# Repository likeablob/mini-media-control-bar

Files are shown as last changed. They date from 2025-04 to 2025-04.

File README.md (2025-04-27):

# mini-media-control-bar

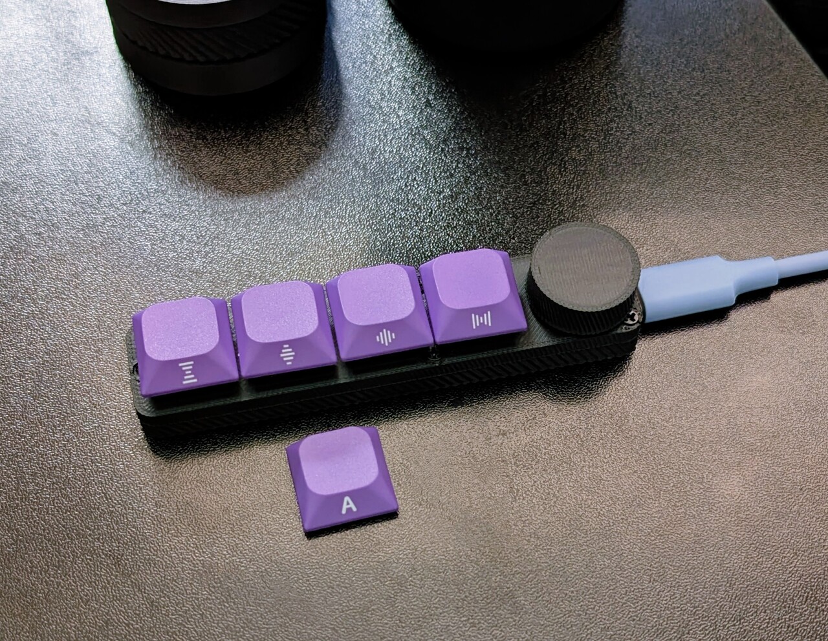
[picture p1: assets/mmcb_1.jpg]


A tiny media control bar based on ESPHome.

- **4 Keys + 1 Rotary Encoder Knob**
- **Acts as a BLE Keyboard with WiFi connectivity (ESP32-C3 Super Mini)**
- **Seamless Home Assistant integration via ESPHome**
- **Customizable 3D Printed Enclosure (designed in OpenSCAD)**

## BOM

| Component | Quantity | Notes |
| :--- | :--- | :--- |
| ESP32-C3 Super Mini | 1 | |
| Low-profile Cherry MX Switches | 4 | |
| Low-profile Keycaps | 4 | |
| Generic Mouse Rotary Encoder | 1 | 3-pin, H5.5mm x W9.5mm |
| Φ1.75mm PLA filament | - | Used as the shaft for the knob.  A short piece is needed. |
| Magnets (Optional) | 2 | Φ3mm x 6mm Neodymium (for mounting) |
| M2 x 6mm Self tapping screws | 5 | |
| Wire | - | |
| LOCTITE | - | |

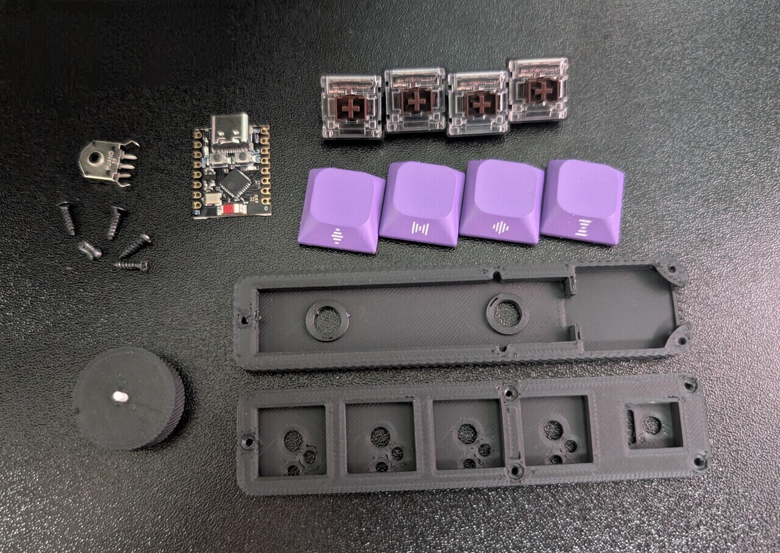
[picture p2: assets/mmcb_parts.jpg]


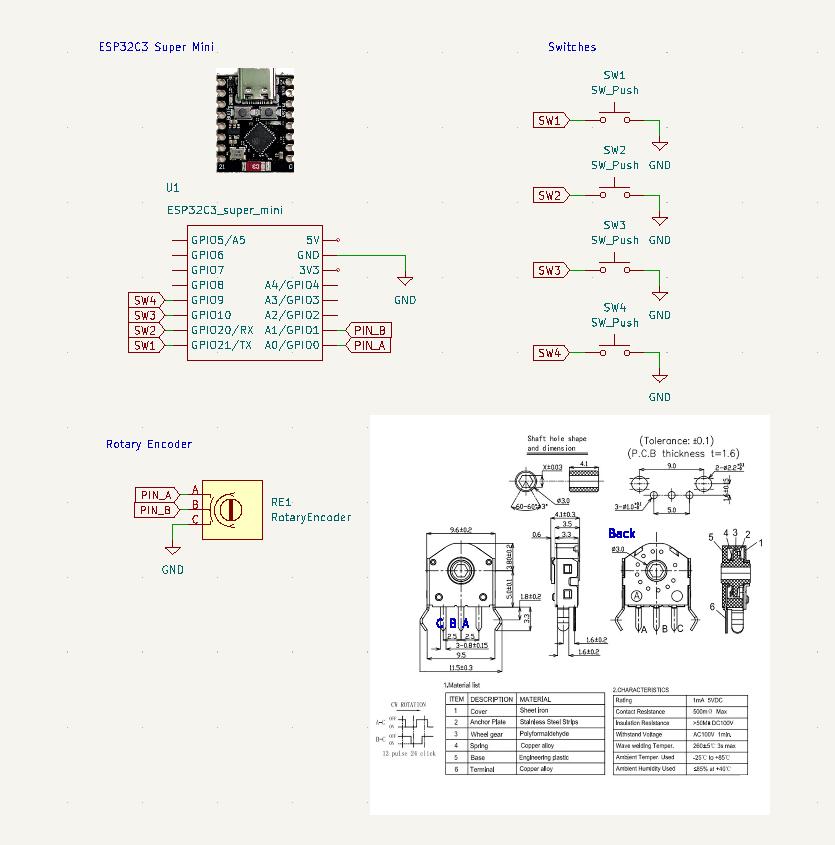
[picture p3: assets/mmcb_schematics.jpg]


## 3D Printed Parts

- See the [`./enclosure`](./enclosure/) directory.

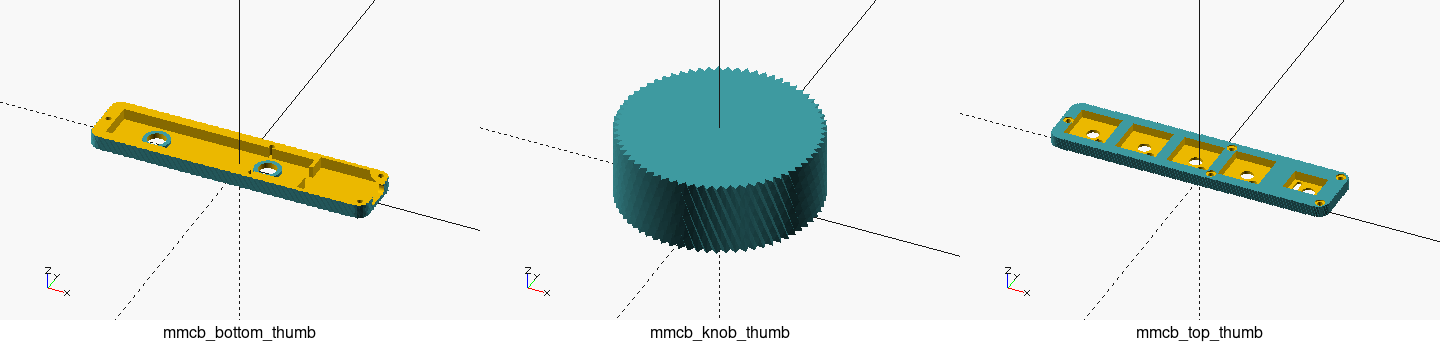
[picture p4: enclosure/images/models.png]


## Software

- The firmware is built using [ESPHome](https://esphome.io/). (`2025.3.3`)
- Reference the package definition [`mmcb.yaml`](./mmcb.yaml) via URL directly or download to your local.

```yaml
# In your esphome config file:
packages:
  mmcb:
    url: https://github.com/likeablob/mini-media-control-bar
    ref: main
    files:
      - path: mmcb.yaml
        vars:
          ble_device_name: "mmcb-1"

# or download to common/mmcb.yaml then reference it
packages:
  mmcb: !include
    file: common/mmcb.yaml
    vars:
      ble_device_name: "mmcb-1"
```

## Usage

| Key | Default | With Meta | Special |
| :--- | :--- | :--- | :--- |
| Key 1 (Left-most) | Meta key | N/A | Double-click: Mute |
| Key 2 | Play/Pause | Mute | |
| Key 3 | Previous track | Left arrow | |
| Key 4 | Next track | Right arrow | |
| Knob | Volume Up/Down | Right/Left arrow | |

See [`mmcb.yaml`](./mmcb.yaml) for configuration options.

## License

MIT

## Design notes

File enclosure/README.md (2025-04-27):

# mini-media-control-bar/case

## Prerequisites

- OpenSCAD (nightly build) 2025.02
- GNU Make
- ImageMagick
- BOSL2 (included as submodule)

## Build

```sh
$ git submodule update --init --recursive

# Generate .scad and .stl files.
$ make all -B

# Generate thumbnail images.
$ make images -B
```

## Parts

| | STL |
| --- | --- |
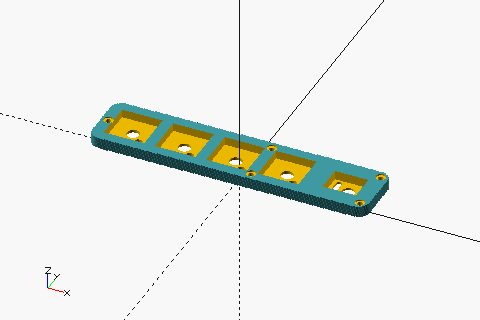
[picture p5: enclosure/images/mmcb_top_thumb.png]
|  | [mmcb_top.stl](./mmcb_top.stl) |
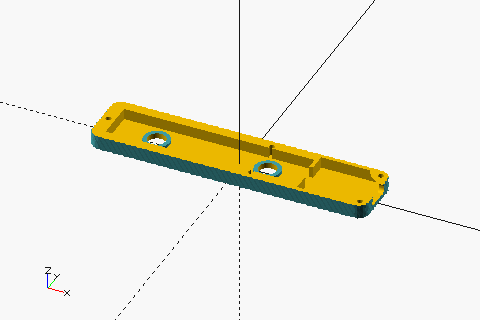
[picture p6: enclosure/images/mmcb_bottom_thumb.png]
|  | [mmcb_bottom.stl](./mmcb_bottom.stl) |
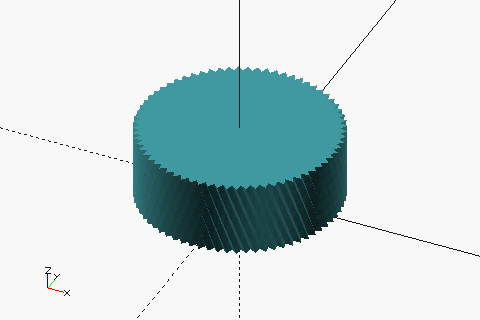
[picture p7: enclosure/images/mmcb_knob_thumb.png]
|  | [mmcb_knob.stl](./mmcb_knob.stl) |

## Print conditions

- 1.75mm PLA
- 0.2mm layer height

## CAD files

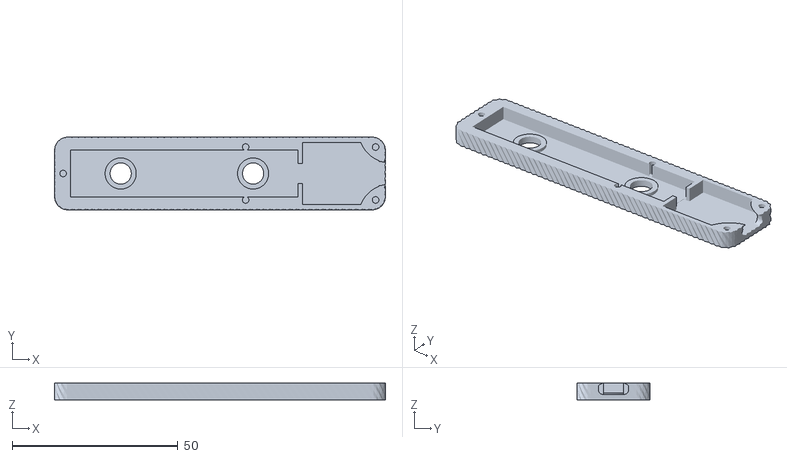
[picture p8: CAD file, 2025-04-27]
enclosure/mmcb_bottom.stl
100.0 x 22.0 x 5.00

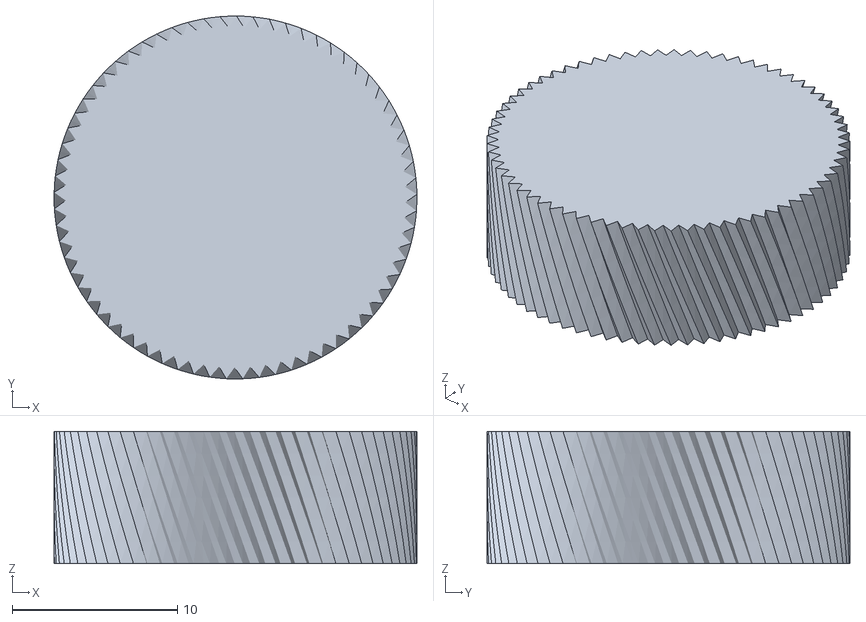
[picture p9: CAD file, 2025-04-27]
enclosure/mmcb_knob.stl
22.0 x 22.0 x 8.00

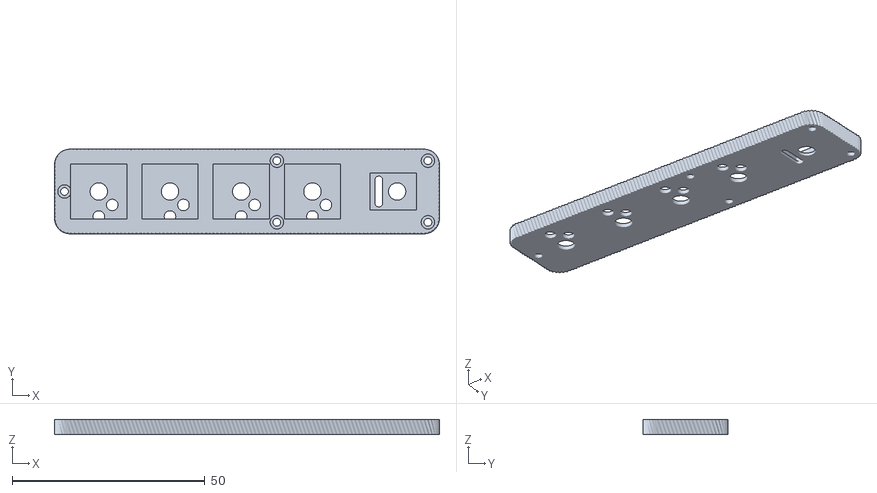
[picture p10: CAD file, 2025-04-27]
enclosure/mmcb_top.stl
100.0 x 22.0 x 4.00

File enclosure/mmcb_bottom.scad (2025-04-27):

include <lib/mmcb.scad>

$fn = 100;

mmcb_bottom();

// % mmcb_top();

% up(MMCB_BODY_SIZE.z + 0.3) pos_knob() mmcb_knob();

% up(10) pos_keys() rect(18);

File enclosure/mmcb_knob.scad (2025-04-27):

include <lib/mmcb.scad>

$fn = 100;

mmcb_knob();

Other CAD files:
enclosure/mmcb_top.scad

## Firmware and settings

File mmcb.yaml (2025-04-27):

external_components:
  - source: github://likeablob/esphome-blekeyboard@6023c6039f17f6c47b1ef4dc953e237f81e206c7

defaults:
  ble_device_name: "mmcb"

ble_keyboard:
  id: mmcb_keyboard
  name: "${ble_device_name}"
  manufacturer_id: "mmcb"
  battery_level: 50
  reconnect: true
  buttons: false
  use_default_libs: false

button:
  - platform: template
    id: btn_media_volume_up
    name: "MEDIA_VOLUME_UP"
    on_press:
      - ble_keyboard.press:
          id: mmcb_keyboard
          code:
            - 32
            - 0
      - ble_keyboard.release:
          id: mmcb_keyboard
          code:
            - 32
            - 0
  - platform: template
    id: btn_media_volume_down
    name: "MEDIA_VOLUME_DOWN"
    on_press:
      - ble_keyboard.press:
          id: mmcb_keyboard
          code:
            - 64
            - 0
      - ble_keyboard.release:
          id: mmcb_keyboard
          code:
            - 64
            - 0
  - platform: template
    id: btn_media_next_track
    name: "MEDIA_NEXT_TRACK"
    on_press:
      - ble_keyboard.press:
          id: mmcb_keyboard
          code:
            - 1
            - 0
      - ble_keyboard.release:
          id: mmcb_keyboard
          code:
            - 1
            - 0
  - platform: template
    id: btn_media_previous_track
    name: "MEDIA_PREVIOUS_TRACK"
    on_press:
      - ble_keyboard.press:
          id: mmcb_keyboard
          code:
            - 2
            - 0
      - ble_keyboard.release:
          id: mmcb_keyboard
          code:
            - 2
            - 0
  - platform: template
    id: btn_media_play_pause
    name: "MEDIA_PLAY_PAUSE"
    on_press:
      - ble_keyboard.press:
          id: mmcb_keyboard
          code:
            - 8
            - 0
      - ble_keyboard.release:
          id: mmcb_keyboard
          code:
            - 8
            - 0
  - platform: template
    id: btn_media_mute
    name: "MEDIA_MUTE"
    on_press:
      - ble_keyboard.press:
          id: mmcb_keyboard
          code:
            - 16
            - 0
      - ble_keyboard.release:
          id: mmcb_keyboard
          code:
            - 16
            - 0
  - platform: template
    id: btn_key_up_arrow
    name: "KEY_UP_ARROW"
    on_press:
      - ble_keyboard.press:
          id: mmcb_keyboard
          code: 0xDA
      - ble_keyboard.release:
          id: mmcb_keyboard
          code: 0xDA
  - platform: template
    id: btn_key_down_arrow
    name: "KEY_DOWN_ARROW"
    on_press:
      - ble_keyboard.press:
          id: mmcb_keyboard
          code: 0xD9
      - ble_keyboard.release:
          id: mmcb_keyboard
          code: 0xD9
  - platform: template
    id: btn_key_left_arrow
    name: "KEY_LEFT_ARROW"
    on_press:
      - ble_keyboard.press:
          id: mmcb_keyboard
          code: 0xD8
      - ble_keyboard.release:
          id: mmcb_keyboard
          code: 0xD8
  - platform: template
    id: btn_key_right_arrow
    name: "KEY_RIGHT_ARROW"
    on_press:
      - ble_keyboard.press:
          id: mmcb_keyboard
          code: 0xD7
      - ble_keyboard.release:
          id: mmcb_keyboard
          code: 0xD7

sensor:
  - platform: rotary_encoder
    name: "Rotary Encoder"
    pin_a:
      number: GPIO1
      mode:
        input: true
        pullup: true
    pin_b:
      number: GPIO0
      mode:
        input: true
        pullup: true
    resolution: 2
    on_clockwise:
      - logger.log: "Turned Clockwise"
      - if:
          condition:
            binary_sensor.is_off:
              id: sw1
          then:
            - button.press:
                id: btn_media_volume_up
          else:
            - button.press:
                id: btn_key_right_arrow
    on_anticlockwise:
      - logger.log: "Turned Anticlockwise"
      - if:
          condition:
            binary_sensor.is_off:
              id: sw1
          then:
            - button.press:
                id: btn_media_volume_down
          else:
            - button.press:
                id: btn_key_left_arrow
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

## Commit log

2025-04-27 feat(*): add files
    [mmcb_bottom.scad, mmcb_bottom.stl, mmcb_knob.scad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]
2025-04-27 feat(package): use ESPHome default rotary_encoder
    - Reverse rotary encoder CW/CCW by swapping pin definition
    - Proper step resolution
    [mmcb.yaml]
2025-04-27 feat(kicad): add kicad project
    - Update schematics image to add rotary encoder spec
    [mmcb.kicad_sch]
